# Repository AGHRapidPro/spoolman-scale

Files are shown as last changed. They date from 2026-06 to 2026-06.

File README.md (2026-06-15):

# ESP32 Spoolman Scale





A headless smart scale that automates 3D-printing filament inventory. Place an
RFID-tagged spool on the scale and the device identifies it, weighs it, computes
how much filament is left, and writes the result back to a
[Spoolman](https://github.com/Donkie/Spoolman) instance over its REST API. No
buttons, no screen, no manual data entry.

<p align="center">
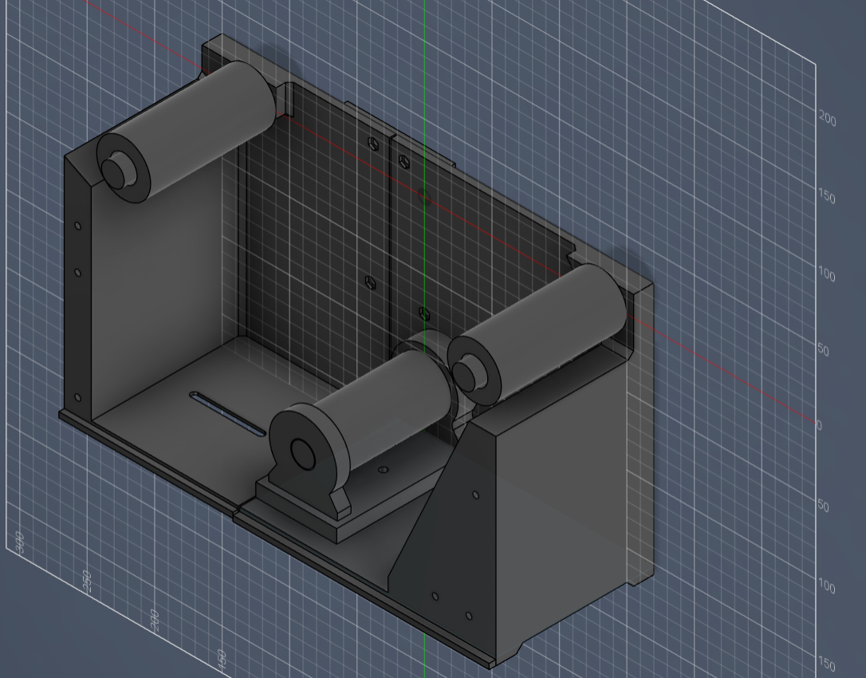
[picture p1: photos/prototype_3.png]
Prototype, general view
  
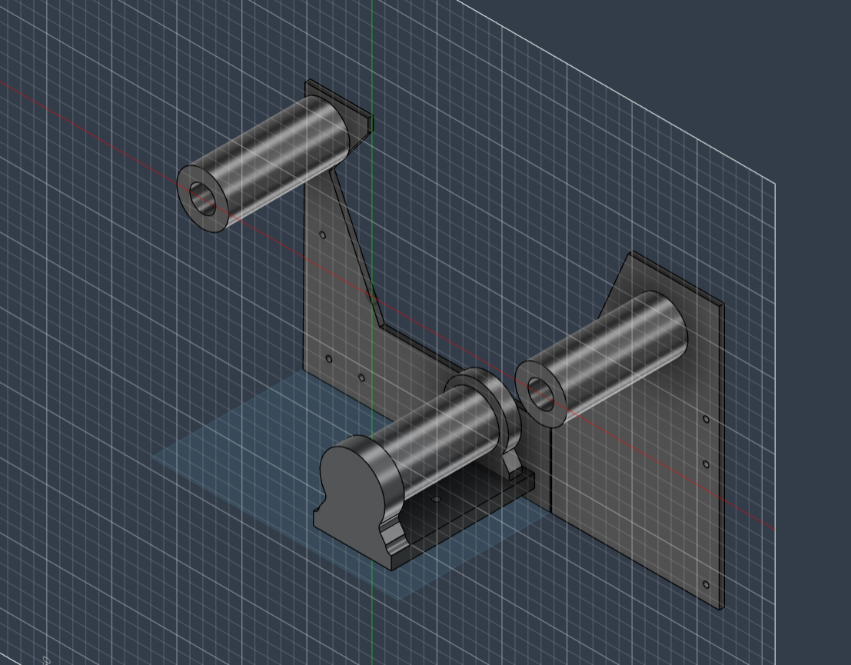
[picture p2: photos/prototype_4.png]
Spool on the scale
  
</p>

## How it works

1. On boot the device initialises the RFID reader and the load cell, loads its
   saved configuration from flash, and connects to WiFi (falling back to a
   configuration portal if no credentials are stored).
2. The main loop waits for an RFID tag. When one appears it reads the tag UID.
3. The device resolves the UID to a Spoolman spool, reads a stabilised weight
   from the load cell, and computes the filament mass.
4. It updates the spool's `used_weight` in Spoolman with a single `PATCH`.
5. Back to waiting for the next tag.

```mermaid
flowchart TD
    A([Power on]) --> B[Init RC522 RFID]
    B --> C[Init HX711: load calibration from NVS + tare]
    C --> D[Load config from NVS]
    D --> E[WiFiManager: connect or open config portal]
    E --> R([Wait for RFID tag])
    R --> P{Tag detected?}
    P -- No --> S[Handle serial commands] --> R
    P -- Yes --> U[Read UID, halt tag]
    U --> W[Read stabilised weight from HX711]
    W --> F["Resolve spool by UID<br/>(in-memory cache, refresh on miss)"]
    F --> G{Spool found?}
    G -- No --> X[Log error, pause] --> R
    G -- Yes --> H["filament = measured − empty spool weight"]
    H --> I["PATCH /spool/{id} { used_weight }"]
    I --> J{HTTP 200?}
    J -- Yes --> K[Updated] --> R
    J -- No --> L[Log error] --> R
```

## Hardware

| Component | Part | Interface |
|---|---|---|
| Microcontroller | Wemos LOLIN S2 Mini (ESP32-S2, single-core) | WiFi |
| Load-cell amplifier | HX711  | I2C |
| Weight sensor | strain-gauge load cell (beam) | analog to HX711 |
| RFID reader | RC522 | software SPI |

> The ESP32-S2 is single-core. The current, mostly-blocking firmware fits
> comfortably on one core, but moving the RFID polling, networking and weighing
> onto separate FreeRTOS tasks (for example on a dual-core ESP32-S3) is the
> natural next step. See the [Roadmap](#roadmap).

### Pin map

Pins are defined in [`src/pins.h`](src/pins.h):

| Peripheral | Signal | GPIO |
|---|---|---|
| RC522 | SS | 13 |
| RC522 | RST | 14 |
| RC522 | MISO | 10 |
| RC522 | MOSI | 11 |
| RC522 | SCK | 12 |
| HX711 | DT | 16 |
| HX711 | SCK | 17 |

A 3D-printable enclosure designed in CAD lives in
[`3d-models/`](3d-models/); it houses the board, the HX711 and the reader, with
the load cell and spool platform on top.

## Software architecture

The firmware is written in modern C++ on the Arduino framework and is organised
around small, single-responsibility classes. `main.cpp` is the composition root:
it instantiates everything once and wires the objects together through
constructor references (dependency injection), which keeps the modules loosely
coupled and easy to reason about.

```cpp
Config          config;
Scale           scale(HX711_DT, HX711_SCK);
RFIDReader      rfid(RFID_SS, RFID_RST, RFID_SCK, RFID_MISO, RFID_MOSI);
SpoolmanClient  spoolman(config);                       // const Config&
CommandHandler  commands(scale, rfid, spoolman, config); // references
```

| Module | Responsibility |
|---|---|
| [`Config`](src/Config.h) | Persistent settings (Spoolman URL) in NVS flash; WiFiManager captive portal |
| [`Scale`](src/Scale.h) | HX711 wrapper: tare, calibration (persisted to NVS), stabilised reads |
| [`RFIDReader`](src/RFIDReader.h) | RFID wrapper over software SPI: `poll` / `halt` / `getUID` |
| [`SpoolmanClient`](src/SpoolmanClient.h) | REST client; UID-to-spool cache; fetch and update operations |
| [`CommandHandler`](src/CommandHandler.h) | Non-blocking serial command parser; delegates to subsystems |
| `SpoolInfo` | Plain data-transfer object describing one spool |

A few design points worth calling out:

- **Client-side RFID cache.** Spoolman has no "look up a spool by RFID" endpoint,
  so `SpoolmanClient` fetches the full spool list once (`GET /spool`), builds an
  in-memory `extra.rfid → id` map, and reuses it. A cache miss triggers exactly
  one refresh (to catch a spool that was just added) before giving up.
- **Stabilised weighing.** Instead of a single reading, `Scale` keeps a sliding
  window of the last few averaged samples and only accepts a measurement once
  the spread drops below a tolerance, with a bounded number of attempts.
- **Zero secrets in source.** WiFi credentials and the Spoolman URL are entered
  once through the WiFiManager portal and stored in NVS; the calibration factor
  is persisted the same way and survives reboots.
- **Responsive serial console.** `CommandHandler` processes at most one command
  per call and is woven into the main loop and the post-update wait windows, so
  diagnostics stay responsive at all times.

## REST API usage

| Method + path | Purpose | Fields used |
|---|---|---|
| `GET /spool` | Fetch the spool list and build the UID cache | `id`, `extra.rfid` |
| `GET /spool/{id}` | Fetch spool details | `spool_weight`, `filament.weight`, `used_weight` |
| `PATCH /spool/{id}` | Write the new usage | body `{ "used_weight": <grams> }` |
| `GET /` | Reachability check | HTTP status |

The new usage is computed as

```
filament_weight = measured_total − empty_spool_weight        (clamped ≥ 0)
used_weight     = full_filament_weight − filament_weight      (clamped ≥ 0)
```

JSON is parsed with ArduinoJson straight from the HTTP stream to keep RAM use low.

## Getting started

### Build and flash

This is a [PlatformIO](https://platformio.org/) project targeting the
`lolin_s2_mini` board. Dependencies are declared in `platformio.ini` and fetched
automatically (`MFRC522`, `HX711`, `ArduinoJson`, `WiFiManager`).

```bash
pio run                 # build
pio run --target upload # flash
pio device monitor      # serial console @ 115200
```

### First-time setup

1. **Configure WiFi and the server.** On first boot (or if it cannot connect)
   the device opens a `SpoolmanScale` WiFi access point with a captive portal.
   Join it and enter your WiFi details plus the Spoolman API URL.
2. **Calibrate the scale.** In the serial monitor send `ONE_KG_SCALE`, then
   follow the prompts: clear the platform and confirm, place a 1000 g reference
   and confirm. The factor is saved to flash.
3. **Tag your spools.** Store each tag's UID in the corresponding spool's
   `extra.rfid` field in Spoolman.
4. **Use it.** Put a tagged spool on the scale and present the tag. The device
   weighs it and updates Spoolman automatically.

### Serial commands

| Command | Action |
|---|---|
| `WEIGHT` | Print the current reading |
| `TARE` | Tare the scale |
| `RFID` | Print the last UID seen |
| `SPL_STATUS` | Check server reachability |
| `WIFI_STATUS` | Print SSID and IP |
| `ONE_KG_SCALE` | Run the interactive 1 kg calibration |

Status and errors are reported on the serial console.

## Deployment

In our setup Spoolman runs as a Docker Compose service behind a reverse proxy
Caddy, provisioned with Ansible across a staging and a production
environment.

## Roadmap

- [ ] Move to a dual-core ESP32 (e.g. ESP32-S3) and split RFID, networking and
      weighing into separate FreeRTOS tasks.
- [ ] Native RFID lookup (or store the spool ID on the tag) to avoid fetching
      the full spool list.
- [ ] Update threshold (debounce) to skip writes for tiny weight changes.
- [ ] OLED display for weight and status.
- [ ] OTA firmware updates.
- [ ] Offline fallback: cache the last known spool data in NVS if WiFi drops.
- [ ] Verify the server certificate (CA pinning) on the HTTPS connection.

## Project layout

```
src/
  main.cpp            orchestration: setup() and loop()
  Config.*            persistent config + WiFiManager portal
  Scale.*             HX711 wrapper, calibration, stabilised reads
  RFIDReader.*        MFRC522 wrapper (software SPI)
  SpoolmanClient.*    REST client + UID cache
  CommandHandler.*    serial command interface
  pins.h              GPIO assignments
3d-models/            enclosure (CAD)
photos/               prototype photos
```

## License

Released under the MIT License. See [LICENSE](LICENSE).

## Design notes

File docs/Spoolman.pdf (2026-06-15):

## AKADEMIA GÓRNICZO – HUTNICZA IM. STANISŁAWA

## STASZICA W KRAKOWIE

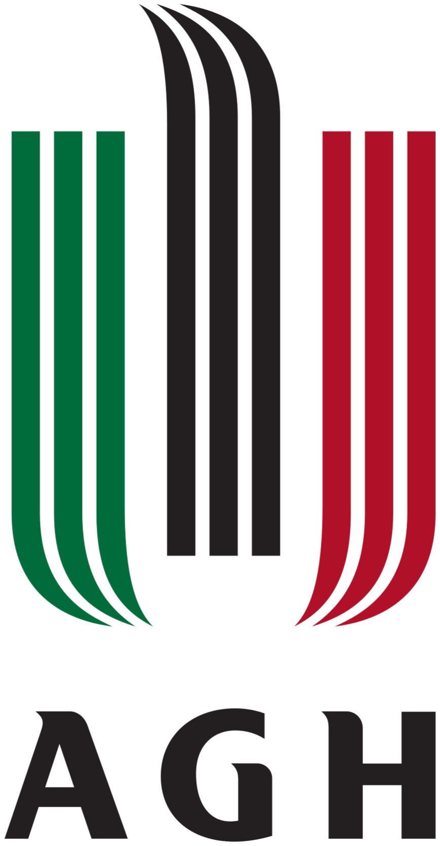
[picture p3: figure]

Department of Computer Science, Electronics and Telecommunications

### Electronics and Telecommunications

Project: System inwentaryzacji filamentów

Subject: Metodyki projektowania i modelowania systemów

Date: 15 czerwca 2026
Instructor: Bogusław Cyganek, prof. dr hab. inż Students:
Aleksander Szczygielski
Marcin Szczepanowski

# Spis treści

Lista oznaczeń | 3
1 Wstęp | 4
2 Wymagania systemowe | 5
3 Funkcjonalność | 6
4 Analiza problemu | 7
5 Projekt techniczny | 9
6 Infrastruktura i wdrożenie | 16
7 Opis realizacji | 18
8 Podręcznik użytkownika | 21
9 Metodologia rozwoju i utrzymania systemu | 22

# Lista oznaczeń

ADC | Analog-to-Digital Converter (przetwornik analogowo-cyfrowy)
API | Application Programming Interface (interfejs programistyczny)
CAD | Computer-Aided Design (projektowanie wspomagane komputerowo)
CA | Certificate Authority (urząd certyfikacji)
DNS | Domain Name System
DTO | Data Transfer Object (obiekt transferu danych)
ESP32 | Mikrokontroler firmy Espressif z wbudowanym WiFi/BT
HTTP | Hypertext Transfer Protocol
HTTPS HTTP zabezpieczony warstwą TLS
JSON | JavaScript Object Notation
NVS | Non-Volatile Storage (partycja pamięci nieulotnej ESP32)
OOP | Object-Oriented Programming (programowanie obiektowe)
OTA | Over-the-Air (aktualizacja oprogramowania zdalnie)
REST | Representational State Transfer
RFID | Radio-Frequency Identification
SPI | Serial Peripheral Interface
SRP | Single Responsibility Principle
TLS | Transport Layer Security
UID | Unique Identifier (unikalny identyfikator tagu RFID)

# Rozdział 1

# Wstęp

Niniejszy dokument opisuje projekt oraz działanie inteligentnej wagi opartej na mikrokontrolerze ESP32, przeznaczonej do zarządzania szpulami filamentu do druku 3D. System współpracuje ze Spoolman, czyli otwartoźródłowym menedżerem inwentarza filamentu (https://github.com/Donkie/Spoolman), (https://github.com/Donkie/Spoolman) poprzez jego API typu REST, a do identyfikacji poszczególnych szpul wykorzystuje tagi RFID przyklejone do każdej z nich.
Głównym celem urządzenia jest automatyzacja śledzenia masy pozostałego filamentu. Gdy szpula zostaje położona na wadze, a jej tag RFID zbliżony do czytnika, urządzenie pobiera z bazy Spoolman dane o szpuli, mierzy jej masę całkowitą, oblicza masę samego filamentu i zapisuje zaktualizowaną wartość zużycia z powrotem do bazy. Dzięki temu stan magazynowy filamentu jest aktualizowany bez ręcznego ważenia i wpisywania danych.
Instancja Spoolman działa na serwerze w sieci laboratoryjnej koła naukowego (home-lab oparty na Proxmoksie), pod adresem spoolman.aghrapid.top. Kod układowy urządzenia jest wersjonowany w repozytorium https://github.com/AGHRapidPro/spoolman-scale. Raport opisuje zarówno warstwę sprzętową i programową samego urządzenia, jak i infrastrukturę serwerową, z którą się ono komunikuje.

# Rozdział 2

# Wymagania systemowe

1. Urządzenie po włączeniu łączy się ze skonfigurowaną siecią WiFi. Jeśli żadne dane logowania nie zostały zapisane lub połączenie się nie powiedzie, otwierany jest portal konfiguracyjny (captive portal) o nazwie SpoolmanScale, w którym użytkownik podaje dane sieci oraz adres serwera Spoolman. W przypadku złego wpisania danych lub chęci zmiany sieci, wymagane jest wymazanie pamięci flash microcontrolera w celu usunięcia danych zapisanych w partycji LittleFS.
2. Konfiguracja (adres URL serwera Spoolman oraz współczynnik kalibracji wagi) jest przechowywana w pamięci nieulotnej NVS i odczytywana przy każdym uruchomieniu.
3. Urządzenie identyfikuje szpule filamentu za pomocą czytnika RFID RC522, odczytując unikalny identyfikator (UID) tagu.
4. Aby powiązać UID z rekordem szpuli, urządzenie pobiera z API Spoolman pełną listę szpul i buduje w pamięci mapę odwzorowującą UID (pole extra.rfid) na identyfikator szpuli. Mapa jest tworzona raz i wykorzystywana ponownie przy kolejnych odczytach, a po nietrafieniu jednorazowo odświeżana. Szczegóły dopasowanej szpuli pobierane są dopiero osobnym żądaniem.
5. Urządzenie mierzy masę szpuli przy użyciu belki tensometrycznej sterowanej przez wzmacniacz HX711 oraz wyznacza stabilną wartość uśrednioną z wielu próbek.
6. Na podstawie pomiaru urządzenie oblicza masę filamentu (masa całkowita pomniejszona o masę pustej szpuli) i aktualizuje rekord w bazie Spoolman żądaniem PATCH.
7. Pętla główna działa w sposób ciągły, po każdym cyklu oczekując na kolejny tag RFID, bez konieczności ponownego uruchamiania urządzenia.
8. Urządzenie udostępnia zestaw komend diagnostycznych przez port szeregowy, w tym interaktywną kalibrację wzorcem 1 kg, a stan pracy i komunikaty błędów raportuje na konsoli szeregowej.

# Rozdział 3

# Funkcjonalność

- Łączność WiFi z portalem konfiguracyjnym oparta o bibliotekę WiFiManager, z automatycznym łączeniem i zapisem ustawień w NVS (czyli partycji littleFS).
- Identyfikacja szpuli RFID polegająca na odczycie UID tagu z czytnika RC522.
- Wyszukiwanie szpuli w Spoolman, które ze względu na brak w API zapytania po RFID pobiera listę wszystkich szpul, buduje w pamięci mapę UID do identyfikatora szpuli, a następnie pobiera szczegóły konkretnego rekordu.
- Ważenie belką tensometryczną przez HX711, z uśrednianiem próbek oraz algorytmem stabilizacji odczytu.
- Automatyczna aktualizacja zużycia filamentu w bazie poprzez żądanie PATCH aktualizujące pole used_weight.
- Obsługa błędów obejmująca logowanie braku szpuli lub serwera oraz jednorazowe odświeżenie pamięci podręcznej w razie nietrafienia.
- Interfejs komend szeregowych pozwalający odczytać masę, wykonać tarowanie, sprawdzić stan WiFi i serwera oraz uruchomić kalibrację.
- Trwała pętla pracy działająca bez przerwy pomiędzy kolejnymi pomiarami.

# Rozdział 4

# Analiza problemu

### 4.1 Identyfikacja szpuli

Każda fizyczna szpula filamentu ma przyklejony tag RFID. Czytnik RC522 odczytuje sprzętowy UID tagu i zamienia go na łańcuch szesnastkowy. Zasadniczym problemem jest powiązanie tego UID z rekordem szpuli w Spoolman, ponieważ API Spoolman nie udostępnia bezpośredniego zapytania w rodzaju „znajdź szpulę po RFID”.
Przyjęte rozwiązanie wykorzystuje pole extra.rfid rekordu szpuli, w którym zapisany jest UID tagu. Klient pobiera listę wszystkich szpul jednym żądaniem GET /spool, a następnie buduje w pamięci mapę extra.rfid do identyfikatora szpuli. Dalsza praca opiera się już na tej pamięci podręcznej, dzięki czemu kolejne odczyty tagów nie wymagają ponownego pobierania całej listy. W razie nietrafienia (na przykład gdy szpula została właśnie dodana) wykonywane jest jedno odświeżenie mapy i ponowna próba dopasowania.

### 4.2 Pomiar masy

Sygnał z belki tensometrycznej jest wzmacniany i przetwarzany przez wzmacniacz HX711. Zliczenia przetwornika są przeliczane na gramy przy użyciu współczynnika kalibracji ustawionego funkcją set_scale. W celu redukcji szumu pojedynczy odczyt jest średnią z N próbek:

m =

1
N

X

N

i=1

ri | (4.1)

gdzie ri to kolejne odczyty przeliczone już na gramy. Aby uzyskać powtarzalny wynik, zastosowano algorytm stabilizacji oparty o okno ostatnich pięciu odczytów. Jeżeli różnica wartości maksymalnej i minimalnej spadnie poniżej zadanej tolerancji ∆s, odczyt uznaje się za stabilny i zwraca środek przedziału:

mstab =

mmin + mmax
2
, | mmax − mmin < ∆s | (4.2)

Domyślnie ∆s = 1,5 g, a algorytm wykonuje do trzydziestu prób; jeśli odczyt się nie ustabilizuje, zwracana jest ostatnia wartość wraz z ostrzeżeniem. Współczynnik kalibracji wyznacza się procedurą interaktywną: po wytarowaniu pustej wagi na platformie umieszcza się wzorzec 1000 g, a współczynnik obliczany jest jako iloraz średniego wskazania i masy wzorca, po czym zostaje zapisany w NVS.

### 4.3 Model danych i aktualizacja zużycia

Z rekordu szpuli pobierane są trzy istotne pola: spool_weight (masa pustej szpuli), filament.weight (masa filamentu dla pełnej szpuli) oraz used_weight (dotychczas zużyta masa filamentu). Masa filamentu na zmierzonej szpuli oraz nowa wartość zużycia wyznaczane są następująco:

mfil = max(0, mstab − mszpula) | (4.3)
mused = max(0, mfil,total − mfil) | (4.4)

Tak wyliczone used_weight jest zapisywane do bazy. W bieżącej wersji aktualizacja następuje po każdym poprawnym pomiarze, bez progu różnicy; wartości ujemne są przycinane do zera, co zabezpiecza przed błędnym zapisem w razie niedoważenia.

# Rozdział 5

# Projekt techniczny

### 5.1 Architektura sprzętowa

Rdzeniem urządzenia jest moduł Wemos LOLIN S2 Mini oparty o układ ESP32-S2. Warto podkreślić, że ESP32-S2 jest mikrokontrolerem jednordzeniowym. Bieżąca, w dużej mierze blokująca architektura oprogramowania (oparta o opóźnienia i krótkie pętle aktywnego oczekiwania) mieści się na pojedynczym rdzeniu i okazała się wystarczająca dla obecnej funkcjonalności. Przy planowanej rozbudowie systemu, w szczególności przy jednoczesnym odpytywaniu czytnika RFID, obsłudze sieci i ważeniu w osobnych zadaniach FreeRTOS, zalecana będzie migracja na mocniejszy układ dwurdzeniowy, na przykład ESP32-S3.
Do pomiaru masy służy belka tensometryczna połączona ze wzmacniaczem HX711, komunikującym się z mikrokontrolerem dwuprzewodowo (przez I2C). Identyfikację szpul realizuje czytnik RC522. Czytnik jest podłączony przez programowy interfejs SPI. Przypisanie pinów zebrano w tabeli 5.1.

Tabela 5.1: Przypisanie pinów GPIO (plik pins.h)

Peryferium | Sygnał GPIO
RC522 (RFID) SS | 13
RC522 (RFID) RST | 14
RC522 (RFID) MISO | 10
RC522 (RFID) MOSI | 11
RC522 (RFID) SCK | 12
HX711 (waga) | DT | 16
HX711 (waga) | SCK | 17

Tabela 5.2: Komponenty sprzętowe urządzenia

Komponent | Model | Interfejs
Mikrokontroler | Wemos LOLIN S2 Mini (ESP32-S2, jednordzeniowy) UART
Wzmacniacz wagi HX711 (24-bit ADC) | cyfrowy 2-przewodowy
Czytnik RFID | RC522 | programowy SPI
Czujnik masy | belka tensometryczna | analogowy do HX711

### 5.2 Architektura oprogramowania (programowanie obiektowe)

Oprogramowanie urządzenia napisano w C++ budowanego narzędziem PlatformIO. Kod podzielono na pięć klas oraz prostą strukturę przenoszącą dane, a punktem spinającym całość jest plik main.cpp. Każda klasa odpowiada za jeden, jasno wydzielony obszar odpowiedzialności, zgodnie z zasadą pojedynczej odpowiedzialności (SRP):

- Config obsługuje trwałą konfigurację (adres URL Spoolman) w pamięci nieulotnej oraz uruchamia portal WiFiManager.
- Scale opakowuje przetwornik HX711, realizując tarowanie, kalibrację z zapisem w pamięci nieulotnej oraz stabilny odczyt masy.
- RFIDReader opakowuje układ czytnika nad programowym SPI i udostępnia metody poll, halt oraz getUID.
- SpoolmanClient jest klientem HTTP REST; utrzymuje pamięć podręczną mapowania UID na identyfikator szpuli i realizuje operacje pobrania oraz aktualizacji rekordu.
- CommandHandler to nieblokujący parser komend przychodzących z portu szeregowego, delegujący żądania do odpowiednich podsystemów.
- SpoolInfo jest strukturą przenoszącą dane jednej szpuli (identyfikator, masa pustej szpuli, masa filamentu, zużycie).

Zależności pomiędzy klasami widoczne są wprost w sposobie tworzenia obiektów w pliku main.cpp. Obiekty są komponowane raz, na poziomie modułu, a zależności wstrzykiwane przez referencje w konstruktorach:

Config | config ;
Scale | scale ( HX711_DT , HX711_SCK ) ;
RFIDReader | rfid ( RFID_SS , RFID_RST , RFID_SCK , RFID_MISO , RFID_MOSI ) ;
SpoolmanClient | spoolman ( config ) ; | // const Config &
CommandHandler | commands ( scale , rfid , spoolman , config ) ; // referencje

Listing 5.1: Kompozycja obiektów i wstrzykiwanie zależności w main.cpp

W projekcie świadomie zastosowano kilka technik programowania obiektowego, które faktycznie występują w kodzie. Enkapsulacja polega na ukryciu detali implementacyjnych za prywatnymi polami i metodami pomocniczymi, takimi jak _persist, _refreshCache, _baseUrl, _dispatch czy _saveCalibration, przy zwięzłym interfejsie publicznym. Kompozycja i wstrzykiwanie zależności przez referencje (const Config&, Scale&, RFIDReader&, SpoolmanClient&) zapewniają luźne powiązanie modułów: na przykład SpoolmanClient przy każdym żądaniu odczytuje aktualny adres z Config, więc zmiana ustawień w portalu działa natychmiast, bez ponownej inicjalizacji klienta. Poprawność stałych (const-correctness) widać w metodach dostępowych spoolmanUrl() const oraz getUID() const, w referencjach const i w konstruktorze explicit SpoolmanClient. Klasy pełnią rolę warstwy abstrakcji sprzętu, ukrywając biblioteki producentów (HX711, MFRC522, WiFiManager, HTTPClient) za jednolitym interfejsem domeny problemu.

### 5.2.1 Diagram klas

Rysunek 5.1 przedstawia diagram klas wraz z zależnościami. Przerywana ramka grupuje obiekty komponowane w main.cpp. Linia przerywana oznacza zależność przez wstrzykniętą referencję (relacja „używa”), a linia ciągła relację tworzenia obiektu danych SpoolInfo.

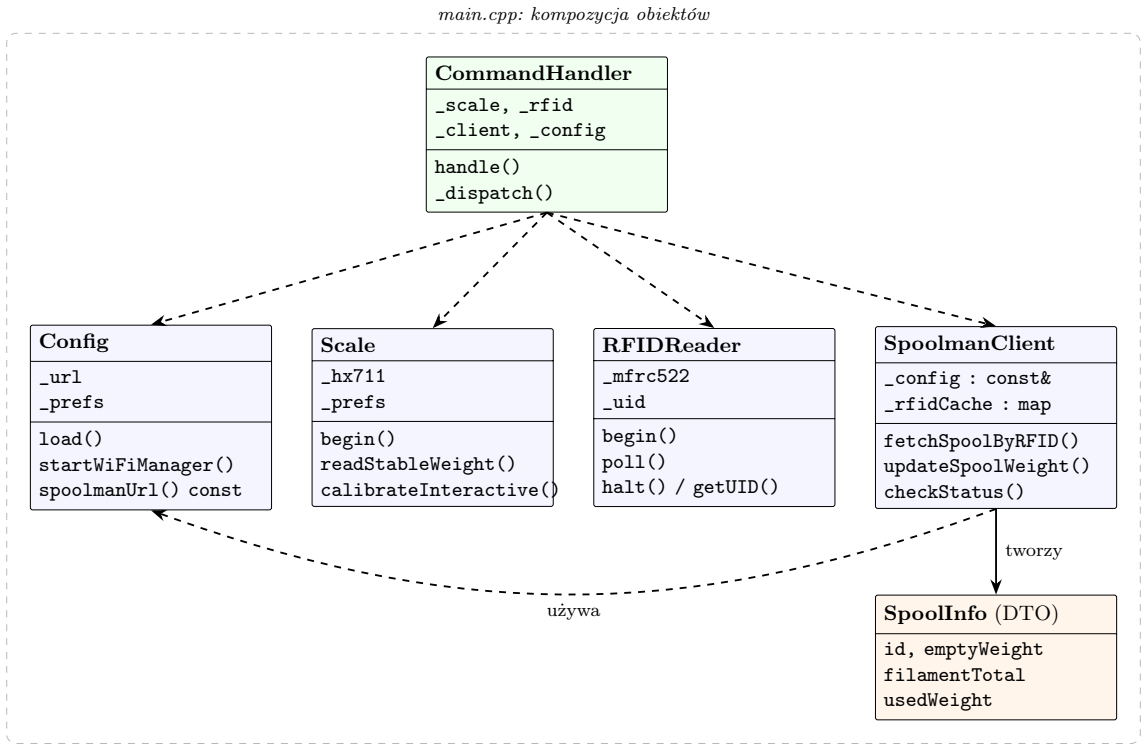
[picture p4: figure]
main.cpp: kompozycja obiektów; CommandHandler; _scale, _rfid _client, _config; handle() _dispatch(); Config; _url _prefs; load() startWiFiManager() spoolmanUrl() const; Scale; _hx711 _prefs; begin() readStableWeight() calibrateInteractive(); RFIDReader; _mfrc522 _uid; begin() poll() halt() / getUID(); SpoolmanClient; _config : const& _rfidCache : map; fetchSpoolByRFID() updateSpoolWeight() checkStatus(); SpoolInfo (DTO); id, emptyWeight filamentTotal usedWeight; używa; tworzy

Rysunek 5.1: Diagram klas oprogramowania urządzenia (kompozycja i zależności)

### 5.2.2 Architektura warstwowa

Z punktu widzenia organizacji modułów oprogramowanie układa się w trzy warstwy (rysunek 5.2): warstwę bibliotek sprzętowych i sieciowych, warstwę klas opakowujących domenę problemu oraz warstwę orkiestracji w main.cpp. Klasy domenowe zależą wyłącznie od bibliotek poniżej, a warstwa orkiestracji spina je w przepływ pracy urządzenia.

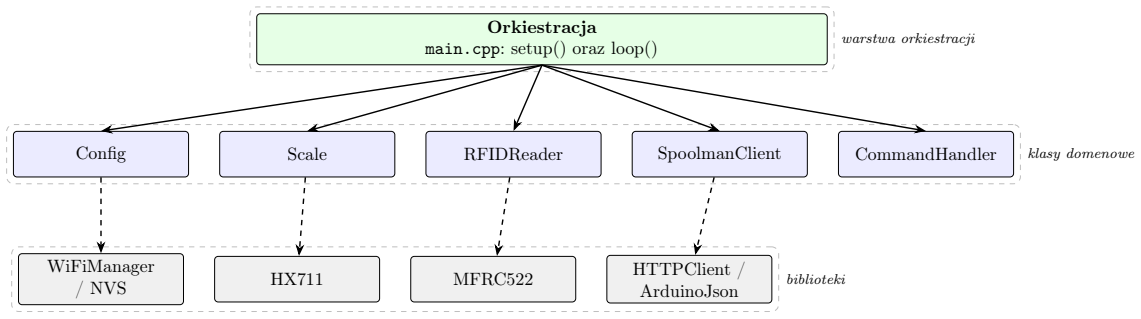
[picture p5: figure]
warstwa orkiestracji; klasy domenowe; biblioteki; Orkiestracja main.cpp: setup() oraz loop(); Config; Scale; RFIDReader; SpoolmanClient; CommandHandler; WiFiManager; / NVS; MFRC522; HTTPClient /; ArduinoJson

Rysunek 5.2: Warstwowa architektura oprogramowania urządzenia

### 5.3 Schemat operacyjny

Rysunek 5.3 przedstawia pełny przebieg pracy urządzenia, od inicjalizacji peryferiów po pętlę pomiarową.

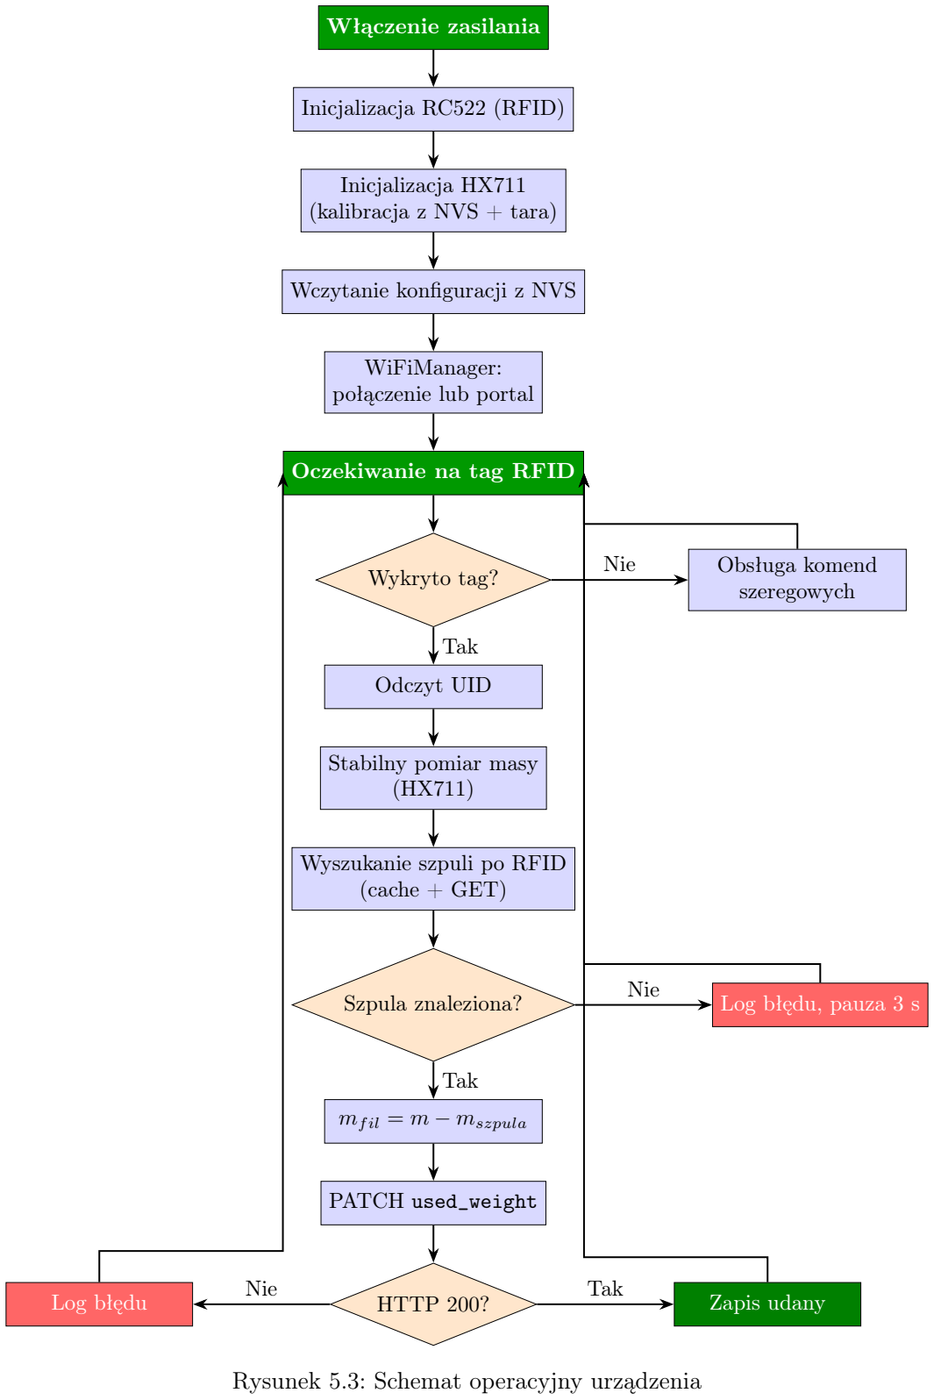
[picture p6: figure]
Włączenie zasilania; Inicjalizacja RC522 (RFID); Inicjalizacja HX711 (kalibracja z NVS + tara); Wczytanie konfiguracji z NVS; WiFiManager: połączenie lub portal; Oczekiwanie na tag RFID; Wykryto tag?; Obsługa komend; szeregowych; Odczyt UID; Stabilny pomiar masy (HX711); Wyszukanie szpuli po RFID (cache + GET); Szpula znaleziona?; Log błędu, pauza 3 s; mf il = m − mszpula; PATCH used_weight; Log błędu; HTTP 200?; Zapis udany; Nie; Tak; Rysunek 5.3: Schemat operacyjny urządzenia

### 5.4 Zasada działania API

Komunikacja z serwerem opiera się o REST API Spoolman po protokole HTTP. Adres bazowy pochodzi z konfiguracji i jest normalizowany (uzupełniany o ukośnik końcowy) przez metodę _baseUrl. Klient wykorzystuje trzy operacje robocze oraz jedno żądanie diagnostyczne, zestawione w tabeli 5.3.

Tabela 5.3: Operacje API Spoolman używane przez urządzenie

Metoda + zasób | Cel | Przetwarzane pola
GET /spool | pobranie listy szpul i zbudowanie mapy cache id, extra.rfid
GET /spool/{id} | pobranie szczegółów szpuli | spool_weight, | filament.weight,
| | used_weight
PATCH /spool/{id} zapis nowego zużycia | treść JSON { used_weight }
GET / (bazowy) | sprawdzenie dostępności serwera | kod odpowiedzi HTTP

Ładunki JSON są przetwarzane biblioteką ArduinoJson, z dokumentami o rozmiarach dobranych do roli (większy bufor na listę szpul, mniejsze na pojedynczy rekord i na treść żądania PATCH). Diagram sekwencji na rysunku 5.4 ilustruje pełny cykl od odczytu tagu po zapis zaktualizowanego zużycia. Kluczowy jest tu krok pośredni: wobec braku zapytania po RFID w API, urządzenie najpierw pobiera listę szpul i lokalnie odwzorowuje UID na identyfikator, a dopiero potem sięga po szczegóły i zapisuje wynik.

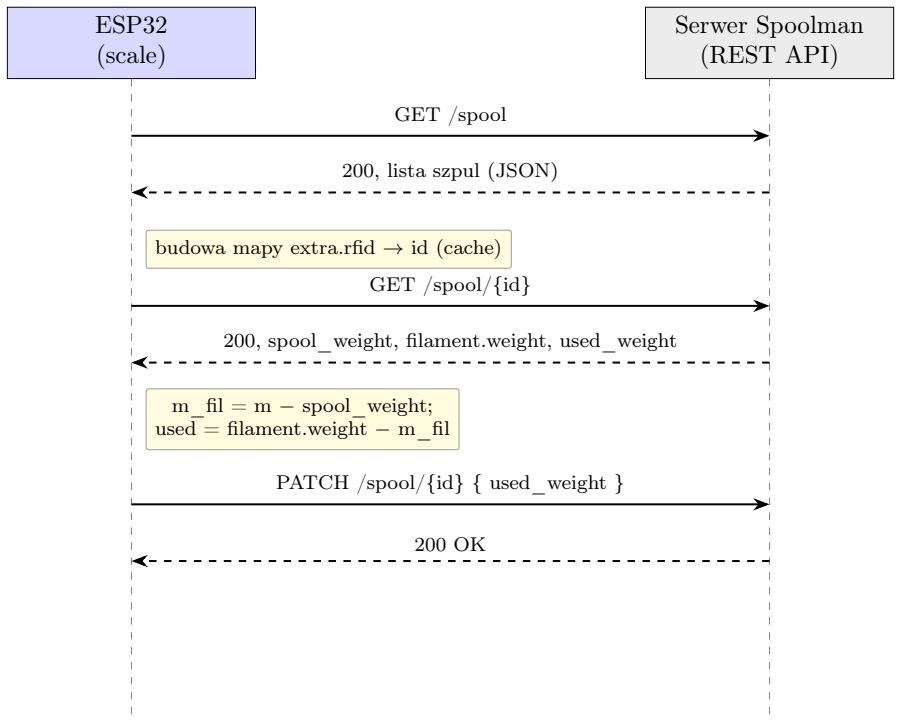
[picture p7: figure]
ESP32 (scale); Serwer Spoolman (REST API); GET /spool; 200, lista szpul (JSON); budowa mapy extra.rfid → id (cache); GET /spool/{id}; 200, spool_weight, filament.weight, used_weight; m_fil = m − spool_weight; used = filament.weight − m_fil; PATCH /spool/{id} { used_weight }

Rysunek 5.4: Diagram sekwencji wymiany z API Spoolman

### 5.5 Konfiguracja

Urządzenie nie przechowuje danych wrażliwych w kodzie źródłowym. Dane sieci WiFi oraz adres serwera Spoolman wprowadza się jednorazowo w portalu konfiguracyjnym WiFiManager, a adres zapisywany jest w przestrzeni spoolman pamięci NVS. Współczynnik kalibracji wagi jest przechowywany w osobnej przestrzeni scale. Listing 5.2 pokazuje rejestrację dodatkowego parametru portalu oraz zapis ustawień przez funkcję zwrotną.

WiFiManagerParameter paramUrl (" url ",
" Spoolman URL (e.g. http ://192.168.1.100:7912/ api /v1)", _url . c_str () , 100) ;
wm . addParameter (& paramUrl ) ;

wm . setSaveParamsCallback ([&]() {
_url = paramUrl . getValue () ;
_persist () ; | // zapis do NVS
}) ;
wm . autoConnect (" SpoolmanScale ") ; // SSID portalu

Listing 5.2: Parametr portalu i zapis konfiguracji (Config.cpp)

### 5.6 Model 3D obudowy

Obudowa urządzenia została zaprojektowana w środowisku CAD (model źródłowy SpoolmanScale_test_model w repozytorium) i wykonana techniką druku 3D. Mieści ona moduł ESP32, wzmacniacz HX711
oraz czytnik RC522, a na górze udostępnia platformę, na której opiera się belka tensometryczna
i ważona szpula. Wizualizację modelu z programu CAD przedstawia rysunek ??, a zdjęcia wydrukowanej obudowy zamieszczono w rozdziale dotyczącym realizacji.

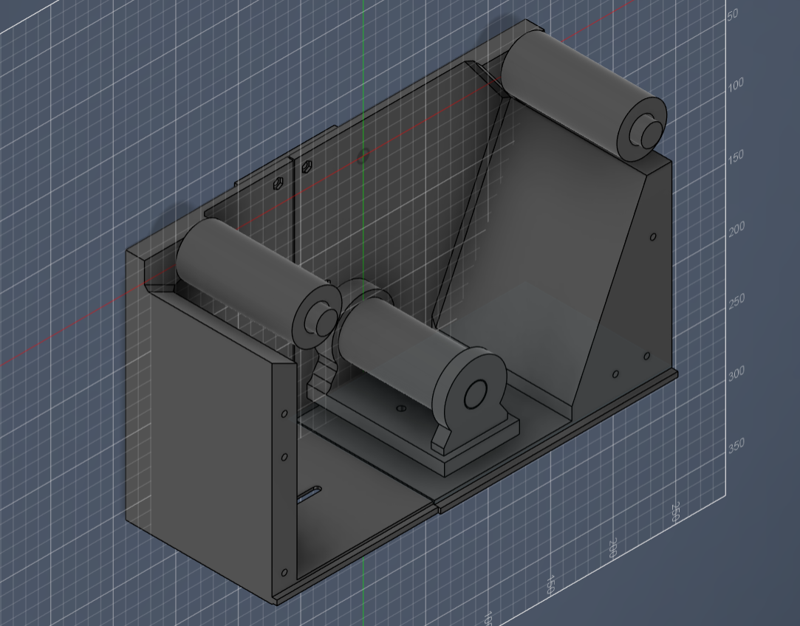
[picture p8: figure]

Rysunek 5.5: Model 3D obudowy (prototyp, ulegnie zmianie ze względu na brak odporności na wstrząsy)

# Rozdział 6

# Infrastruktura i wdrożenie

Instancja Spoolman jest częścią współdzielonego stosu Dockerowego laboratorium koła naukowego, zarządzanego przez Ansible i wystawionego na świat przez serwer pośredniczący Caddy. Rysunek 6.1 przedstawia ogólny obraz operacji sieciowych i wdrożenia: urządzenie ESP32 łączy się po WiFi i protokole HTTP z publicznym adresem, który serwer Caddy kieruje do kontenera Spoolman wewnątrz sieci Dockera. Stos jest wdrażany z repozytorium plików compose przez

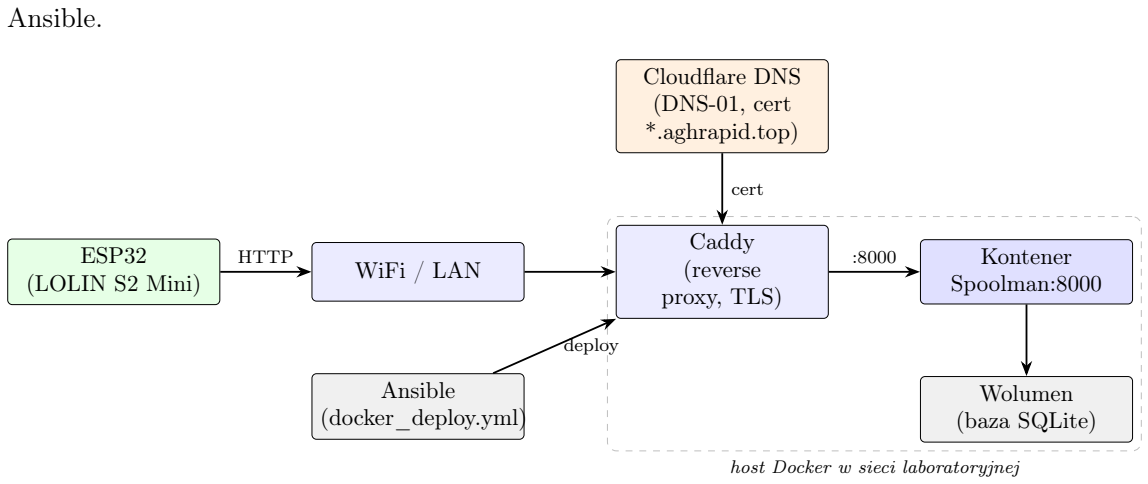
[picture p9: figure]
Ansible.; host Docker w sieci laboratoryjnej; ESP32; (LOLIN S2 Mini); WiFi / LAN; Caddy (reverse proxy, TLS); Kontener Spoolman:8000; Wolumen (baza SQLite); Cloudflare DNS (DNS-01, cert *.aghrapid.top); Ansible (docker_deploy.yml); HTTP; cert; deploy

Rysunek 6.1: Architektura wdrożenia i operacji sieciowych

### 6.1 Operacje sieciowe

Urządzenie łączy się z serwerem przez publiczny adres po HTTP - tylko w sieci lokalnej.

### 6.2 Usługa Docker

Spoolman działa jako usługa docker compose obok innych narzędzi laboratorium (między innymi Vaultwarden, Wekan, LLDAP, SuiteCRM) na hoście w sieci wewnętrznej. Definicję usługi przedstawia listing 6.1.

spoolman :
image : ghcr . io / donkie / spoolman : latest container_name : spoolman
user : root
restart : unless - stopped
volumes :
- ./ spoolman :/ root /. local / share / spoolman

environment :
- TZ = Europe / Warsaw
entrypoint : []
command :
- uvicorn
- spoolman . main : app
- -- host
- 0.0.0.0
- -- port
- " 8000 "

Listing 6.1: Definicja usługi Spoolman w Docker Compose

Dane trwałe (baza SQLite oraz konfiguracja) są przechowywane w katalogu ./spoolman/ na hoście i montowane do kontenera w /root/.local/share/spoolman.

### 6.3 Reverse proxy (Caddy)

Serwer Caddy z modułem Cloudflare obsługuje terminację TLS dla wszystkich usług laboratorium, używając certyfikatu typu wildcard dla domeny *.aghrapid.top wystawionego metodą DNS-01. Wirtualne hosty Spoolman zestawiono w tabeli 6.1; oba kierują ruch do spoolman:8000 wewnątrz sieci Dockera.

Tabela 6.1: Wirtualne hosty Caddy dla Spoolman

Środowisko | Adres publiczny
Produkcja | https://spoolman.aghrapid.top
Przedprodukcja https://spoolman-preprod.aghrapid.top

### 6.4 Wdrożenie Ansible

Stos jest wdrażany playbookiem Ansible (docker_deploy.yml) wymierzonym w dwie grupy hostów zdefiniowane w inventory.yml (tabela 6.2). Playbook synchronizuje pliki compose z katalogu ../docker-compose/<host>/ do /opt/ na maszynie docelowej za pomocą rsync, wstrzykuje plik secrets.env, uwierzytelnia się w rejestrze Dockera, po czym uruchamia stos modułem community.docker.docker_compose_v2. Sekrety są usuwane z hosta docelowego bezpośrednio po wdrożeniu.

Tabela 6.2: Cele wdrożenia Ansible

Środowisko | Host Ansible | Wewnętrzny DNS
Produkcja | docker | docker.rapid.internal
Przedprodukcja docker-preprod | docker-preprod.rapid.internal

# Rozdział 7

# Opis realizacji

Oprogramowanie zrealizowano na ESP32, budowanym i wgrywanym poprzez narzędzie PlatformIO (płytka lolin_s2_mini, prędkość monitora 115200). Wykorzystane biblioteki zewnętrzne zadeklarowano w pliku platformio.ini: MFRC522 do obsługi RFID, HX711 do wagi, ArduinoJson do przetwarzania JSON oraz WiFiManager do konfiguracji sieci. Kod podzielono na pliki źródłowe odpowiadające klasom opisanym w rozdziale technicznym, z osobnym plikiem pins.h zawierającym przypisanie pinów.
W trakcie realizacji powstało kilka rozwiązań wartych podkreślenia, które faktycznie znajdują się w kodzie.

Algorytm stabilnego odczytu masy. Zamiast pojedynczego pomiaru zastosowano okno przesuwne ostatnich pięciu uśrednionych odczytów. Pomiar uznawany jest za wiarygodny dopiero wtedy, gdy rozstęp w oknie spadnie poniżej zadanej tolerancji; algorytm wykonuje do trzydziestu prób i raportuje bieżącą zmienność na konsoli.

float variation = maxVal - minVal ;
if ( variation < maxVariation ) {
float stable = ( minVal + maxVal ) / 2.0 f ; return stable ;
}

Listing 7.1: Sprawdzanie stabilności odczytu (Scale.cpp)

Pamięć podręczna RFID po stronie klienta. Ponieważ API Spoolman nie udostępnia wyszukiwania po RFID, klient pobiera listę szpul i buduje mapę extra.rfid do identyfikatora. Przy nietrafieniu wykonywane jest jedno odświeżenie i ponowna próba, co obsługuje przypadek świeżo dodanej szpuli bez stałego pobierania całej listy.

Trwałość w pamięci NVS. Zarówno współczynnik kalibracji wagi, jak i adres serwera Spoolman są zapisywane w pamięci nieulotnej przez bibliotekę Preferences, dzięki czemu ustawienia przetrwają restart i utratę zasilania.

Portal konfiguracyjny WiFiManager. Pierwsza konfiguracja odbywa się bez przekompilowania kodu: urządzenie udostępnia sieć SpoolmanScale z formularzem WiFi oraz dodatkowym polem na adres Spoolman, zapisywanym przez funkcję zwrotną.

Nieblokujący interfejs komend szeregowych. Klasa CommandHandler przetwarza co najwyżej jedną kompletną komendę na wywołanie i jest wpleciona w pętlę główną oraz w okna oczekiwania, dzięki czemu komendy diagnostyczne pozostają responsywne nawet podczas przerw po aktualizacji.

Zdjęcia zmontowanego prototypu urządzenia przedstawiono na rysunku 7.2. Miejsce na zdjęcia finalnej, wydrukowanej obudowy pozostawiono na rysunku ??.

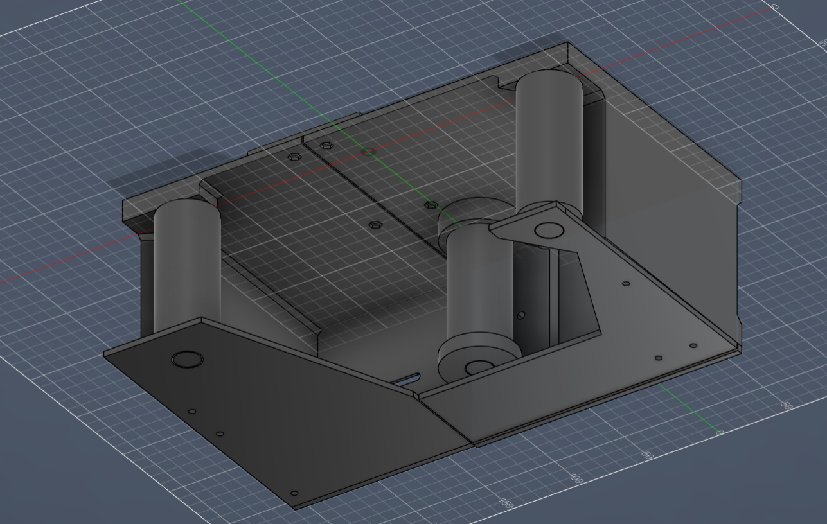
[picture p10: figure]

(a) Widok wewnątrz, można zobaczyć ułożenie rolek przytrzymujące szpule
(b) Widok ukazujący miejsce na belkę tensometryczną


(c) Wskazanie zaczepu dolnego belki tensometrycznej


(d) Pozostałe mocowania (pomijając główne elementy konstrukcyjne)

Rysunek 7.1: Prototyp urządzenia

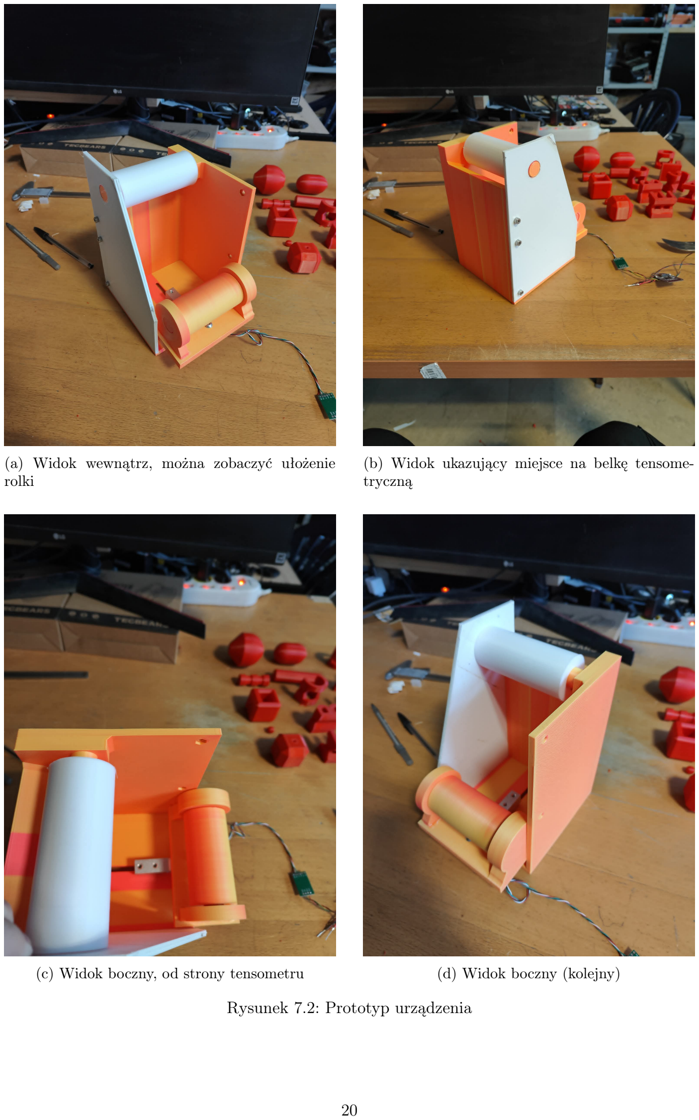
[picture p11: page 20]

(a) Widok wewnątrz, można zobaczyć ułożenie rolki
(b) Widok ukazujący miejsce na belkę tensometryczną
(c) Widok boczny, od strony tensometru | (d) Widok boczny (kolejny)

Rysunek 7.2: Prototyp urządzenia

# Rozdział 8

# Podręcznik użytkownika

Korzystanie z urządzenia sprowadza się do kilku kroków. Przy pierwszym uruchomieniu, jeśli nie zapisano konfiguracji, urządzenie udostępnia sieć WiFi SpoolmanScale; należy się z nią połączyć i w otwartym formularzu podać dane własnej sieci oraz adres serwera Spoolman, a następnie zapisać ustawienia. Wagę kalibruje się jednorazowo komendą ONE_KG_SCALE wpisaną w monitor portu szeregowego: po zdjęciu obciążenia potwierdza się tarowanie, po czym umieszcza wzorzec 1000 g i ponownie potwierdza. UID tagu każdej szpuli należy przypisać do jej rekordu w Spoolman (pole extra.rfid).
Codzienne użycie polega na położeniu oznaczonej tagiem szpuli na wadze i zbliżeniu tagu do czytnika. Urządzenie odczyta UID, zmierzy masę, pobierze dane szpuli i zaktualizuje jej zużycie w bazie. Dostępne są też komendy diagnostyczne wpisywane przez port szeregowy: WEIGHT (bieżące wskazanie), TARE (tarowanie), RFID (ostatni UID), SPL_STATUS (dostępność serwera Spoolman) oraz WIFI_STATUS (stan sieci).

# Rozdział 9

# Metodologia rozwoju i utrzymania systemu

Dalszy rozwój systemu obejmuje zarówno warstwę sprzętową, jak i programową. Najważniejszym kierunkiem jest migracja na mocniejszy, dwurdzeniowy układ ESP (na przykład ESP32-S3). Obecny LOLIN S2 Mini jest jednordzeniowy, a architektura oprogramowania jest w dużej mierze blokująca; dwurdzeniowy mikrokontroler pozwoliłby rozdzielić odpytywanie RFID, obsługę sieci i ważenie na osobne zadania FreeRTOS, a tym samym poprawić responsywność i otworzyć drogę do aktualizacji OTA.

□ Migracja na układ dwurdzeniowy (ESP32-S3) i podział pracy na zadania FreeRTOS.

□ Docelowa strategia identyfikacji RFID: natywne wyszukiwanie po stronie serwera lub zapis identyfikatora wprost na tagu, aby uniknąć pobierania pełnej listy szpul.

□ Próg aktualizacji (debouncing) ograniczający zbędne zapisy przy niewielkich wahaniach pomiaru.

□ Wyświetlacz OLED z informacją zwrotną o masie i statusie.

□ Aktualizacja oprogramowania w trybie OTA.

□ Tryb offline z buforowaniem ostatnich danych szpuli w NVS na wypadek utraty WiFi.

□ Weryfikacja certyfikatu serwera (przypięcie CA) w połączeniu HTTPS.

# Bibliografia

[1] Donkie, Spoolman: Filament Spool Manager, GitHub. https://github.com/Donkie/Spoolman (https://github.com/Donkie/Spoolman)
[2] AGH Rapid Prototyping, spoolman-scale: firmware repository, GitHub. https://github.com/AGHRapidPro/spoolman-scale (https://github.com/AGHRapidPro/spoolman-scale)
[3] Espressif Systems, ESP32-S2 Technical Reference Manual, 2023. https://www.espressif.com/ (https://www.espressif.com/)
[4] AVIA Semiconductor, HX711: 24-Bit Analog-to-Digital Converter for Weigh Scales, Datasheet, 2016.
[5] NXP Semiconductors, MFRC522: Standard performance MIFARE and NTAG Frontend, Datasheet Rev. 3.9, 2016.
[6] B. Blanchon, ArduinoJson: C++ JSON library for embedded systems. https://arduinojson.org/
[7] tzapu, WiFiManager: ESP WiFi configuration portal. https://github.com/tzapu/WiFiManager (https://github.com/tzapu/WiFiManager)
[8] PlatformIO Labs, PlatformIO: professional collaborative platform for embedded development. https://platformio.org/

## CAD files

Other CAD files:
3d-models/SpoolmanScale_test_model.f3d

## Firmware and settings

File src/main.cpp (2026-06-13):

#include <Arduino.h>
#include <WiFi.h>
#include "pins.h"
#include "Config.h"
#include "Scale.h"
#include "RFIDReader.h"
#include "SpoolmanClient.h"
#include "CommandHandler.h"

Config          config;
Scale           scale(HX711_DT, HX711_SCK);
RFIDReader      rfid(RFID_SS, RFID_RST, RFID_SCK, RFID_MISO, RFID_MOSI);
SpoolmanClient  spoolman(config);
CommandHandler  commands(scale, rfid, spoolman, config);

void setup() {
    Serial.begin(115200);
    delay(10000);
    Serial.println("\n\n========================================");
    Serial.println("Spoolman Headless Scale (LOLIN S2 Mini)");
    Serial.println("========================================\n");

    rfid.begin();
    scale.begin();
    config.load();
    config.startWiFiManager();

    Serial.print("[WiFi] Connected to "); Serial.println(WiFi.SSID());
    Serial.print("[WiFi] IP address: ");  Serial.println(WiFi.localIP());
    Serial.print("[WiFi] Spoolman URL: "); Serial.println(config.spoolmanUrl());
    Serial.println("\nReady. Place an RFID-tagged spool on the scale.\n");
}

void loop() {
    commands.handle();

    if (!rfid.poll()) {
        unsigned long start = millis();
        while (!rfid.poll() && (millis() - start < 100)) {
            commands.handle();
            delay(1);
        }
        return;
    }

    Serial.println("\n========================================");
    Serial.print("[RFID] Tag detected, UID: "); Serial.println(rfid.getUID());
    rfid.halt();

    Serial.println("[Scale] Waiting for stable weight...");
    float measuredTotal = scale.readStableWeight(5, 1.5f);
    Serial.print("[Scale] Measured total weight: "); Serial.print(measuredTotal, 2); Serial.println(" g");

    Serial.println("[Spoolman] Fetching spool data...");
    SpoolInfo spool;
    if (!spoolman.fetchSpoolByRFID(rfid.getUID(), spool)) {
        Serial.println("[ERROR] Spool not found or server unreachable.");
        unsigned long t = millis();
        while (millis() - t < 3000) { commands.handle(); delay(10); }
        return;
    }

    float filamentWeight = measuredTotal - spool.emptyWeight;
    if (filamentWeight < 0) filamentWeight = 0;
    Serial.print("[Calc] Filament weight = "); Serial.print(filamentWeight, 2); Serial.println(" g (total - empty)");

    Serial.println("[Spoolman] Updating weight...");
    if (spoolman.updateSpoolWeight(spool.id, filamentWeight, spool.filamentTotal)) {
        Serial.println("[SUCCESS] Weight updated on server.\n");
    } else {
        Serial.println("[ERROR] Failed to update weight.\n");
    }

    unsigned long t = millis();
    while (millis() - t < 3000) { commands.handle(); delay(10); }
}

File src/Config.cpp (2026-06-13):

#include "Config.h"
#include <WiFiManager.h>
#include <WiFi.h>

Config::Config() {}

void Config::load() {
    _prefs.begin("spoolman", true);
    _url    = _prefs.getString("url",    "");
    _prefs.end();

    if (_url.length() > 0) {
        Serial.print("[Config] Loaded Spoolman URL: "); Serial.println(_url);
    } 
    else {
        Serial.println("[Config] No saved Spoolman URL.");
    }
}

void Config::startWiFiManager() {
    if (!_url.isEmpty() && WiFi.status() == WL_CONNECTED) return;

    Serial.println("[WiFi] Starting configuration portal...");
    WiFiManager wm;
    WiFiManagerParameter paramUrl("url", "Spoolman URL (e.g. http://192.168.1.100:7912/api/v1)", _url.c_str(), 100);
    wm.addParameter(&paramUrl);

    wm.setSaveParamsCallback([&]() {
        _url    = paramUrl.getValue();
        _persist();
        Serial.println("[WiFi] Spoolman config saved.");
    });

    wm.autoConnect("SpoolmanScale");
    Serial.println("[WiFi] Configuration finished.");
}

void Config::_persist() {
    _prefs.begin("spoolman", false);
    _prefs.putString("url",    _url);
    _prefs.end();
}

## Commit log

2026-06-12 Added base ESP32 code (minimal)
2026-06-13 fixed printing
2026-06-13 Added 3D models
    [SpoolmanScale_test_model.f3d]

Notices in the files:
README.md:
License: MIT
